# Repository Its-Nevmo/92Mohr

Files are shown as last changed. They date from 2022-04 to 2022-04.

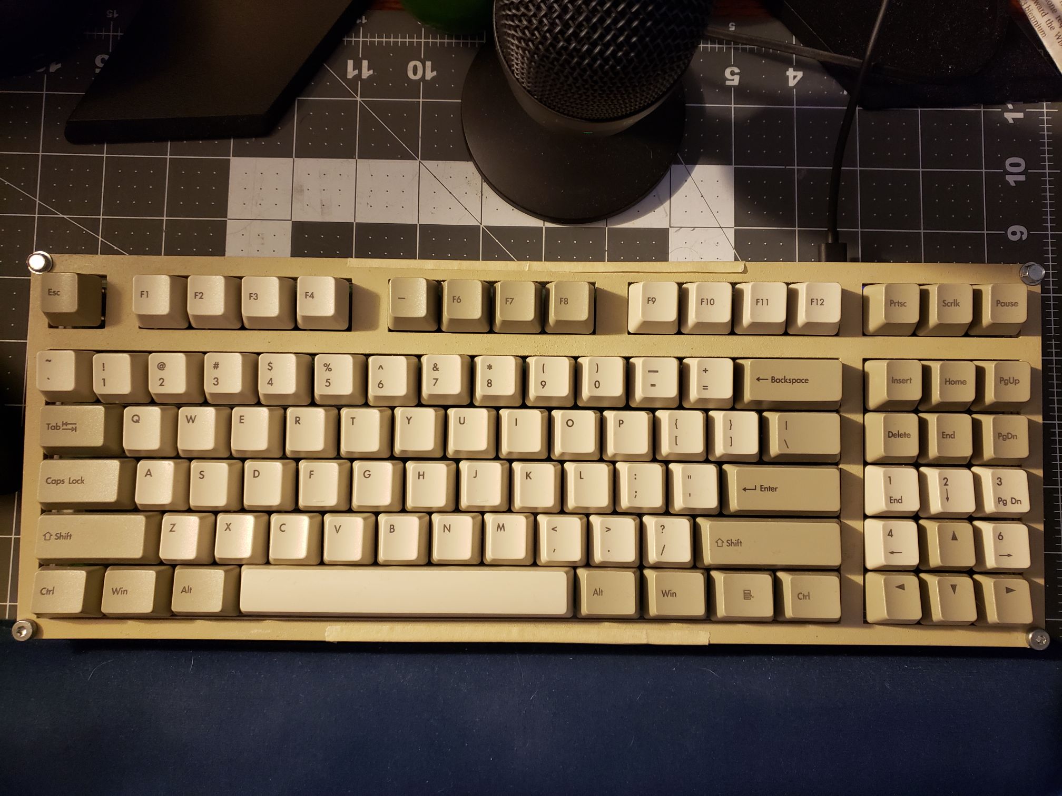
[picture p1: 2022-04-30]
20220419_165109.jpg

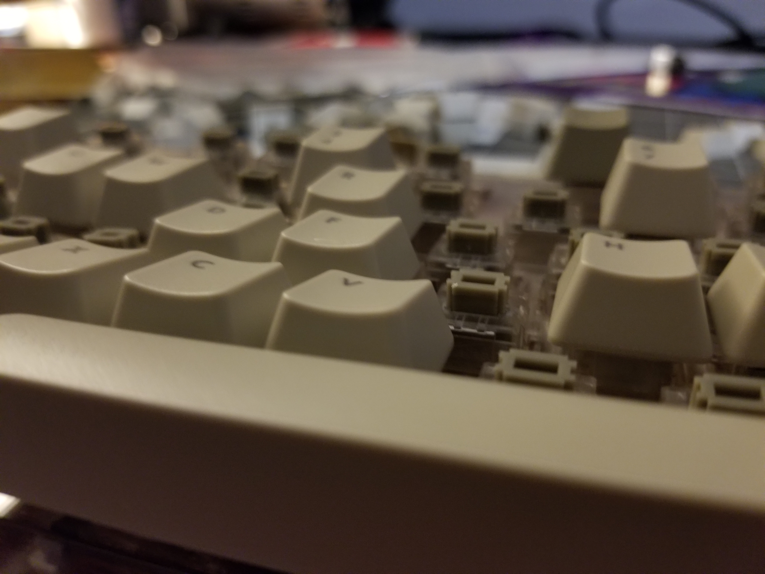
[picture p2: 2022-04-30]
20200909_171346.jpg

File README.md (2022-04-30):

# 92Mohr

Probably my largest project to date, I present the 92Mohr. It's a TKL+, as I call it, because it follows the standard 87-key tenkeyless keyboard layout plus an additional five keys above the arrow keys (which I would think would have been done before, but I guess not). Utilizing the ALPS keyswitch standard, I used Matias Quiet Click switches with KbParadise Vintage PBT keycaps. 

While the original design had an integrated microcontroller, I learned the hard way that SMD soldering is not easy if you do not have the correct tools. As such, the most recent active revision, V3, relies on a socketed microcontroller. In this case, I'm using the Elite-C, but a Pro Micro would work as well. I'm currently in the process of developing a fourth version, featuring an integrated microcontroller, universal switch sockets for people who want MX switches instead of ALPS, and possibly a rotary switch and OLED display.

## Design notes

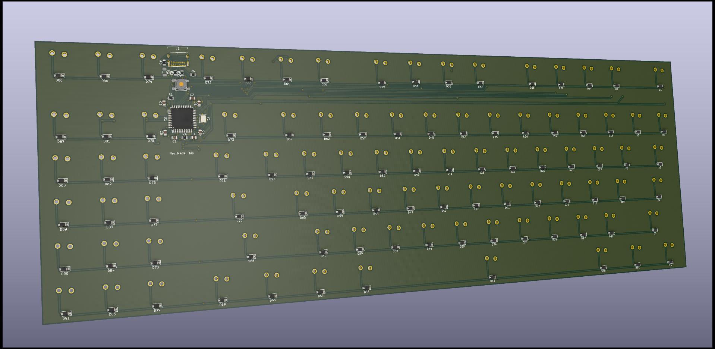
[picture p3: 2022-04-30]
customKeyboard/customKeyboard/customKeyboard.jpg

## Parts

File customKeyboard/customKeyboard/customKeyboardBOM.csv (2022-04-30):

Id | Designator | Package | Quantity | Designation | Supplier and ref
1 | ALPS74,ALPS1,ALPS92,ALPS91,ALPS90,ALPS89,ALPS88,ALPS87,ALPS86,ALPS85,ALPS84,ALPS83,ALPS82,ALPS81,ALPS80,ALPS79,ALPS78,ALPS77,ALPS76,ALPS75,ALPS72,ALPS67,ALPS66,ALPS65,ALPS64,ALPS62,ALPS61,ALPS60,ALPS59,ALPS58,ALPS57,ALPS56,ALPS55,ALPS53,ALPS52,ALPS51,ALPS50,ALPS49,ALPS47,ALPS46,ALPS45,ALPS44,ALPS43,ALPS42,ALPS41,ALPS40,ALPS39,ALPS38,ALPS37,ALPS36,ALPS35,ALPS34,ALPS32,ALPS31,ALPS30,ALPS29,ALPS28,ALPS27,ALPS26,ALPS25,ALPS24,ALPS23,ALPS22,ALPS21,ALPS20,ALPS19,ALPS17,ALPS16,ALPS15,ALPS14,ALPS13,ALPS12,ALPS10,ALPS9,ALPS8,ALPS7,ALPS2 | ALPS-1U | 77 | ALPS-NoLED
2 | F1 | Fuse_1206_3216Metric | 1 | 500mA
3 | R5,R6 | R_0805_2012Metric | 2 | 5k1
4 | R2,R3 | R_0805_2012Metric | 2 | 22
5 | C7,C6 | C_0805_2012Metric | 2 | 22pF
6 | ALPS70,ALPS6 | ALPS-2.25U | 2 | ALPS-NoLED
7 | Y1 | Crystal_SMD_3225-4Pin_3.2x2.5mm | 1 | 16MHz
8 | U1 | TQFP-44_10x10mm_P0.8mm | 1 | ATmega32U4-AU
9 | SW1 | SKQG-1155865 | 1 | SW_Push
10 | R4,R1 | R_0805_2012Metric | 2 | 10k
11 | J1 | USB_C_GCT_USB4085 | 1 | USB_C_Receptacle_USB2.0
12 | D92,D91,D90,D89,D88,D87,D86,D85,D84,D83,D82,D81,D80,D79,D78,D77,D76,D75,D74,D73,D72,D71,D70,D69,D68,D67,D66,D65,D64,D63,D62,D61,D60,D59,D58,D57,D56,D55,D54,D53,D52,D51,D50,D49,D48,D47,D46,D45,D44,D43,D42,D41,D40,D39,D38,D37,D36,D35,D34,D33,D32,D31,D30,D29,D28,D27,D26,D25,D24,D23,D22,D21,D20,D19,D18,D17,D16,D15,D14,D13,D12,D11,D10,D9,D8,D7,D6,D5,D4,D3,D2,D1 | D_SOD-123 | 92 | D_Small
13 | C5 | C_0805_2012Metric | 1 | 10uF
14 | C4,C3,C2 | C_0805_2012Metric | 3 | 0.1uF
15 | C1 | C_0805_2012Metric | 1 | 1uF
16 | ALPS73 | ALPS-2U | 1 | ALPS-NoLED
17 | ALPS71,ALPS3 | ALPS-1.5U | 2 | ALPS-NoLED
18 | ALPS69,ALPS63,ALPS54,ALPS48,ALPS18,ALPS11,ALPS5 | ALPS-1.25U | 7 | ALPS-NoLED
19 | ALPS68 | ALPS-2.75U | 1 | ALPS-NoLED
20 | ALPS33 | ALPS-6.25U | 1 | ALPS-NoLED
21 | ALPS4 | ALPS-1.75U | 1 | ALPS-NoLED

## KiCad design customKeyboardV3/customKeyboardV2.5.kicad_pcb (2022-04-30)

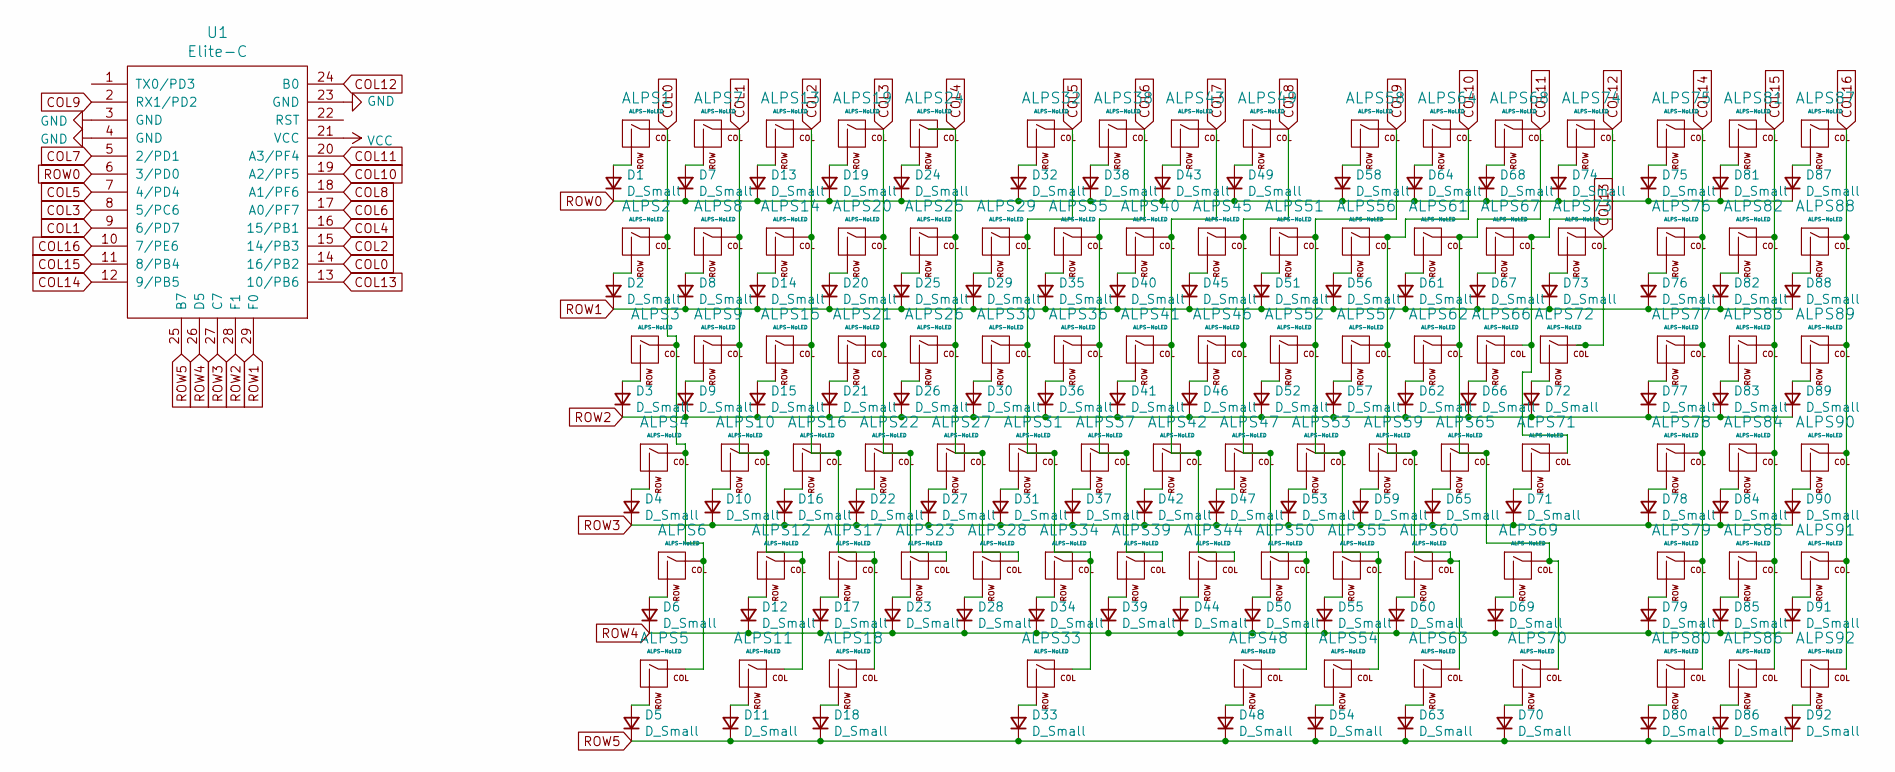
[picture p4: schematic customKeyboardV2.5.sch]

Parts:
ALPS1, ALPS2, ALPS7, ALPS8, ALPS9, ALPS10, ALPS12, ALPS13, ALPS14, ALPS15, ALPS16, ALPS17, ALPS19, ALPS20, ALPS21, ALPS22, ALPS23, ALPS24, ALPS25, ALPS26, ALPS27, ALPS28, ALPS29, ALPS30, ALPS31, ALPS32, ALPS34, ALPS35, ALPS36, ALPS37, ALPS38, ALPS39, ALPS40, ALPS41, ALPS42, ALPS43, ALPS44, ALPS45, ALPS46, ALPS47, ALPS49, ALPS50, ALPS51, ALPS52, ALPS53, ALPS55, ALPS56, ALPS57, ALPS58, ALPS59, ALPS60, ALPS61, ALPS62, ALPS64, ALPS65, ALPS66, ALPS67, ALPS68, ALPS74, ALPS75, ALPS76, ALPS77, ALPS78, ALPS79, ALPS80, ALPS81, ALPS82, ALPS83, ALPS84, ALPS85, ALPS86, ALPS87, ALPS88, ALPS89, ALPS90, ALPS91, ALPS92: ALPS-NoLED; ALPS-1U
ALPS3, ALPS72: ALPS-NoLED; ALPS-1.5U
ALPS4: ALPS-NoLED; ALPS-1.75U
ALPS5, ALPS11, ALPS18, ALPS48, ALPS54, ALPS63, ALPS70: ALPS-NoLED; ALPS-1.25U
ALPS6, ALPS71: ALPS-NoLED; ALPS-2.25U
ALPS33: ALPS-NoLED; ALPS-6.25U
ALPS69: ALPS-NoLED; ALPS-2.75U
ALPS73: ALPS-NoLED; ALPS-2U
D1, D2, D3, D4, D5, D6, D7, D8, D9, D10, D11, D12, D13, D14, D15, D16, D17, D18, D19, D20, D21, D22, D23, D24, D25, D26, D27, D28, D29, D30, D31, D32, D33, D34, D35, D36, D37, D38, D39, D40, D41, D42, D43, D44, D45, D46, D47, D48, D49, D50, D51, D52, D53, D54, D55, D56, D57, D58, D59, D60, D61, D62, D63, D64, D65, D66, D67, D68, D69, D70, D71, D72, D73, D74, D75, D76, D77, D78, D79, D80, D81, D82, D83, D84, D85, D86, D87, D88, D89, D90, D91, D92: D_Small; D_SOD-123
U1: Elite-C; Elite-C-castellated-29pin-holes-nopads

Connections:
COL0: ALPS1.1 (COL), ALPS2.1 (COL), ALPS3.1 (COL), ALPS4.1 (COL), ALPS5.1 (COL), ALPS6.1 (COL), U1.14 (16/PB2)
COL1: ALPS7.1 (COL), ALPS8.1 (COL), ALPS9.1 (COL), ALPS10.1 (COL), ALPS11.1 (COL), ALPS12.1 (COL), U1.9 (6/PD7)
COL2: ALPS13.1 (COL), ALPS14.1 (COL), ALPS15.1 (COL), ALPS16.1 (COL), ALPS17.1 (COL), ALPS18.1 (COL), U1.15 (14/PB3)
COL3: ALPS19.1 (COL), ALPS20.1 (COL), ALPS21.1 (COL), ALPS22.1 (COL), ALPS23.1 (COL), U1.8 (5/PC6)
COL4: ALPS24.1 (COL), ALPS25.1 (COL), ALPS26.1 (COL), ALPS27.1 (COL), ALPS28.1 (COL), U1.16 (15/PB1)
COL5: ALPS29.1 (COL), ALPS30.1 (COL), ALPS31.1 (COL), ALPS32.1 (COL), ALPS33.1 (COL), ALPS34.1 (COL), U1.7 (4/PD4)
COL6: ALPS35.1 (COL), ALPS36.1 (COL), ALPS37.1 (COL), ALPS38.1 (COL), ALPS39.1 (COL), U1.17 (A0/PF7)
COL7: ALPS40.1 (COL), ALPS41.1 (COL), ALPS42.1 (COL), ALPS43.1 (COL), ALPS44.1 (COL), U1.5 (2/PD1)
COL8: ALPS45.1 (COL), ALPS46.1 (COL), ALPS47.1 (COL), ALPS48.1 (COL), ALPS49.1 (COL), ALPS50.1 (COL), U1.18 (A1/PF6)
COL9: ALPS51.1 (COL), ALPS52.1 (COL), ALPS53.1 (COL), ALPS54.1 (COL), ALPS55.1 (COL), ALPS58.1 (COL), U1.2 (RX1/PD2)
COL10: ALPS56.1 (COL), ALPS57.1 (COL), ALPS59.1 (COL), ALPS60.1 (COL), ALPS63.1 (COL), ALPS64.1 (COL), U1.19 (A2/PF5)
COL11: ALPS61.1 (COL), ALPS62.1 (COL), ALPS65.1 (COL), ALPS68.1 (COL), ALPS69.1 (COL), ALPS70.1 (COL), U1.20 (A3/PF4)
COL12: ALPS66.1 (COL), ALPS67.1 (COL), ALPS71.1 (COL), ALPS74.1 (COL), U1.24 (B0)
COL13: ALPS72.1 (COL), ALPS73.1 (COL), U1.13 (10/PB6)
COL14: ALPS75.1 (COL), ALPS76.1 (COL), ALPS77.1 (COL), ALPS78.1 (COL), ALPS79.1 (COL), ALPS80.1 (COL), U1.12 (9/PB5)
COL15: ALPS81.1 (COL), ALPS82.1 (COL), ALPS83.1 (COL), ALPS84.1 (COL), ALPS85.1 (COL), ALPS86.1 (COL), U1.11 (8/PB4)
COL16: ALPS87.1 (COL), ALPS88.1 (COL), ALPS89.1 (COL), ALPS90.1 (COL), ALPS91.1 (COL), ALPS92.1 (COL), U1.10 (7/PE6)
GND: U1.3 (GND), U1.4 (GND), U1.23 (GND)
unnamed: ALPS1.2 (ROW), D1.2 (A)
unnamed: ALPS2.2 (ROW), D2.2 (A)
unnamed: ALPS3.2 (ROW), D3.2 (A)
unnamed: ALPS4.2 (ROW), D4.2 (A)
unnamed: ALPS5.2 (ROW), D5.2 (A)
unnamed: ALPS6.2 (ROW), D6.2 (A)
unnamed: ALPS7.2 (ROW), D7.2 (A)
unnamed: ALPS8.2 (ROW), D8.2 (A)
unnamed: ALPS9.2 (ROW), D9.2 (A)
unnamed: ALPS10.2 (ROW), D10.2 (A)
unnamed: ALPS11.2 (ROW), D11.2 (A)
unnamed: ALPS12.2 (ROW), D12.2 (A)
unnamed: ALPS13.2 (ROW), D13.2 (A)
unnamed: ALPS14.2 (ROW), D14.2 (A)
unnamed: ALPS15.2 (ROW), D15.2 (A)
unnamed: ALPS16.2 (ROW), D16.2 (A)
unnamed: ALPS17.2 (ROW), D17.2 (A)
unnamed: ALPS18.2 (ROW), D18.2 (A)
unnamed: ALPS19.2 (ROW), D19.2 (A)
unnamed: ALPS20.2 (ROW), D20.2 (A)
unnamed: ALPS21.2 (ROW), D21.2 (A)
unnamed: ALPS22.2 (ROW), D22.2 (A)
unnamed: ALPS23.2 (ROW), D23.2 (A)
unnamed: ALPS24.2 (ROW), D24.2 (A)
unnamed: ALPS25.2 (ROW), D25.2 (A)
unnamed: ALPS26.2 (ROW), D26.2 (A)
unnamed: ALPS27.2 (ROW), D27.2 (A)
unnamed: ALPS28.2 (ROW), D28.2 (A)
unnamed: ALPS29.2 (ROW), D29.2 (A)
unnamed: ALPS30.2 (ROW), D30.2 (A)
unnamed: ALPS31.2 (ROW), D31.2 (A)
unnamed: ALPS32.2 (ROW), D32.2 (A)
unnamed: ALPS33.2 (ROW), D33.2 (A)
unnamed: ALPS34.2 (ROW), D34.2 (A)
unnamed: ALPS35.2 (ROW), D35.2 (A)
unnamed: ALPS36.2 (ROW), D36.2 (A)
unnamed: ALPS37.2 (ROW), D37.2 (A)
unnamed: ALPS38.2 (ROW), D38.2 (A)
unnamed: ALPS39.2 (ROW), D39.2 (A)
unnamed: ALPS40.2 (ROW), D40.2 (A)
unnamed: ALPS41.2 (ROW), D41.2 (A)
unnamed: ALPS42.2 (ROW), D42.2 (A)
unnamed: ALPS43.2 (ROW), D43.2 (A)
unnamed: ALPS44.2 (ROW), D44.2 (A)
unnamed: ALPS45.2 (ROW), D45.2 (A)
unnamed: ALPS46.2 (ROW), D46.2 (A)
unnamed: ALPS47.2 (ROW), D47.2 (A)
unnamed: ALPS48.2 (ROW), D48.2 (A)
unnamed: ALPS49.2 (ROW), D49.2 (A)
unnamed: ALPS50.2 (ROW), D50.2 (A)
unnamed: ALPS51.2 (ROW), D51.2 (A)
unnamed: ALPS52.2 (ROW), D52.2 (A)
unnamed: ALPS53.2 (ROW), D53.2 (A)
unnamed: ALPS54.2 (ROW), D54.2 (A)
unnamed: ALPS55.2 (ROW), D55.2 (A)
unnamed: ALPS56.2 (ROW), D56.2 (A)
unnamed: ALPS57.2 (ROW), D57.2 (A)
unnamed: ALPS58.2 (ROW), D58.2 (A)
unnamed: ALPS59.2 (ROW), D59.2 (A)
unnamed: ALPS60.2 (ROW), D60.2 (A)
unnamed: ALPS61.2 (ROW), D61.2 (A)
unnamed: ALPS62.2 (ROW), D62.2 (A)
unnamed: ALPS63.2 (ROW), D63.2 (A)
unnamed: ALPS64.2 (ROW), D64.2 (A)
unnamed: ALPS65.2 (ROW), D65.2 (A)
unnamed: ALPS66.2 (ROW), D66.2 (A)
unnamed: ALPS67.2 (ROW), D67.2 (A)
unnamed: ALPS68.2 (ROW), D68.2 (A)
unnamed: ALPS69.2 (ROW), D69.2 (A)
unnamed: ALPS70.2 (ROW), D70.2 (A)
unnamed: ALPS71.2 (ROW), D71.2 (A)
unnamed: ALPS72.2 (ROW), D72.2 (A)
unnamed: ALPS73.2 (ROW), D73.2 (A)
unnamed: ALPS74.2 (ROW), D74.2 (A)
unnamed: ALPS75.2 (ROW), D75.2 (A)
unnamed: ALPS76.2 (ROW), D76.2 (A)
unnamed: ALPS77.2 (ROW), D77.2 (A)
unnamed: ALPS78.2 (ROW), D78.2 (A)
unnamed: ALPS79.2 (ROW), D79.2 (A)
unnamed: ALPS80.2 (ROW), D80.2 (A)
unnamed: ALPS81.2 (ROW), D81.2 (A)
unnamed: ALPS82.2 (ROW), D82.2 (A)
unnamed: ALPS83.2 (ROW), D83.2 (A)
unnamed: ALPS84.2 (ROW), D84.2 (A)
unnamed: ALPS85.2 (ROW), D85.2 (A)
unnamed: ALPS86.2 (ROW), D86.2 (A)
unnamed: ALPS87.2 (ROW), D87.2 (A)
unnamed: ALPS88.2 (ROW), D88.2 (A)
unnamed: ALPS89.2 (ROW), D89.2 (A)
unnamed: ALPS90.2 (ROW), D90.2 (A)
unnamed: ALPS91.2 (ROW), D91.2 (A)
unnamed: ALPS92.2 (ROW), D92.2 (A)
ROW0: D1.1 (K), D7.1 (K), D13.1 (K), D19.1 (K), D24.1 (K), D32.1 (K), D38.1 (K), D43.1 (K), D49.1 (K), D58.1 (K), D64.1 (K), D68.1 (K), D74.1 (K), D75.1 (K), D81.1 (K), D87.1 (K), U1.6 (3/PD0)
ROW1: D2.1 (K), D8.1 (K), D14.1 (K), D20.1 (K), D25.1 (K), D29.1 (K), D35.1 (K), D40.1 (K), D45.1 (K), D51.1 (K), D56.1 (K), D61.1 (K), D67.1 (K), D73.1 (K), D76.1 (K), D82.1 (K), D88.1 (K), U1.29 (F0)
ROW2: D3.1 (K), D9.1 (K), D15.1 (K), D21.1 (K), D26.1 (K), D30.1 (K), D36.1 (K), D41.1 (K), D46.1 (K), D52.1 (K), D57.1 (K), D62.1 (K), D66.1 (K), D72.1 (K), D77.1 (K), D83.1 (K), D89.1 (K), U1.28 (F1)
ROW3: D4.1 (K), D10.1 (K), D16.1 (K), D22.1 (K), D27.1 (K), D31.1 (K), D37.1 (K), D42.1 (K), D47.1 (K), D53.1 (K), D59.1 (K), D65.1 (K), D71.1 (K), D78.1 (K), D84.1 (K), D90.1 (K), U1.27 (C7)
ROW4: D6.1 (K), D12.1 (K), D17.1 (K), D23.1 (K), D28.1 (K), D34.1 (K), D39.1 (K), D44.1 (K), D50.1 (K), D55.1 (K), D60.1 (K), D69.1 (K), D79.1 (K), D85.1 (K), D91.1 (K), U1.26 (D5)
ROW5: D5.1 (K), D11.1 (K), D18.1 (K), D33.1 (K), D48.1 (K), D54.1 (K), D63.1 (K), D70.1 (K), D80.1 (K), D86.1 (K), D92.1 (K), U1.25 (B7)
VCC: U1.21 (VCC)

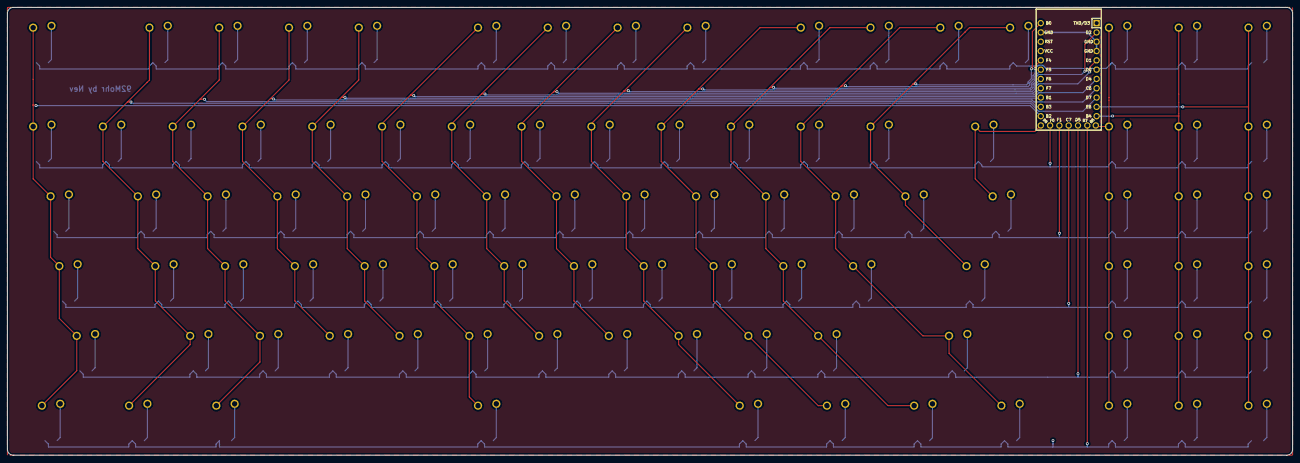
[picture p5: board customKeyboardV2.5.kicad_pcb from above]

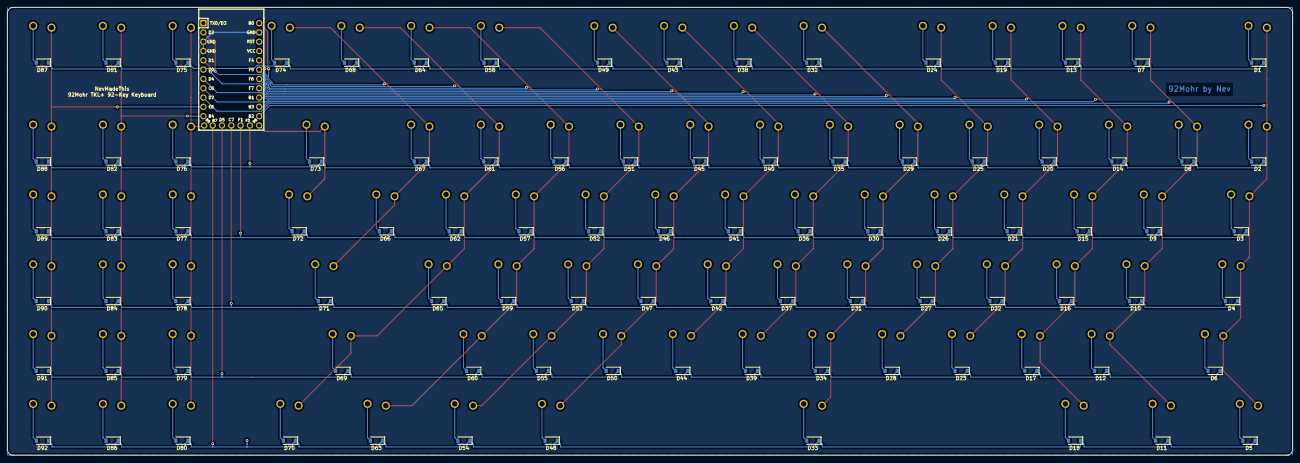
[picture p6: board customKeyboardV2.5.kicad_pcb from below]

Board: 2 copper layers, 350.8 x 122.2 mm, 185 parts (93 on the bottom side), 116 nets.

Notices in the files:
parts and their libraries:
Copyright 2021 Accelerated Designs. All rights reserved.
